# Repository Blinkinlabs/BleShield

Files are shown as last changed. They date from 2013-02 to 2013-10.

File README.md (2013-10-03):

# Blinkinlabs Bluetooth Low Energy Shield

An Arduino shield using the S-Power BG312L BLE module:
http://s-power.com.hk/BG312L.html

This shield is designed for the serial version of the module.

The BLE Shield has plenty of different peripherals that you can use to prototype your own Bluetooth Low Energy designs: three buttons, one RGB led, and an output to control one digital RGB LED strip.

The BLE Shield has been tested on the Arduino Duemilanove, Uno, and Leonardo. It has been confirmed to work with the iPad Mini running the free LightBlue application, and should work fine with iPhone 4S, iPhone5, and iPad Retina running iOS 5 and 6. The iPad 2 does not support Bluetooth 4.0 (BLE). Android support for BLE is unfortunately incomplete but in active development. Support for MacOS, Windows, and Linux is currently untested but seems to be in active development.

We're currently working on demo applications for iOS and computers, but in the mean time, you can communicate with your BLE Shield using the free LightBlue application by Punch Through, available on the app store. There are several other BLE iOS apps available that should work as well.

The BG312L module is based on the [TI CC2541][ti] Bluetooth 4.0 chip. More information, as well as sample iOS code, is available on [TI's Wiki][ti-wiki].

Let us know what cool things you do with the BLE Shield!

# Arduino Library and Demo Sketch

From the `library` folder, copy the `Blinkinlabs_BLEShield` folder to your Arduino `libraries` folder. Restart the Arduino IDE, then open File->Sketchbook->libraries->Blinkinlabs_BLEShield->BLEShield. Upload to your Arduino and follow the instructions on our [website][ble] to connect to the shield using your Bluetooth 4.0 compatible device. Enjoy!

[ti]: http://www.ti.com/product/cc2541
[ti-wiki]: http://processors.wiki.ti.com/index.php/Category:BluetoothLE

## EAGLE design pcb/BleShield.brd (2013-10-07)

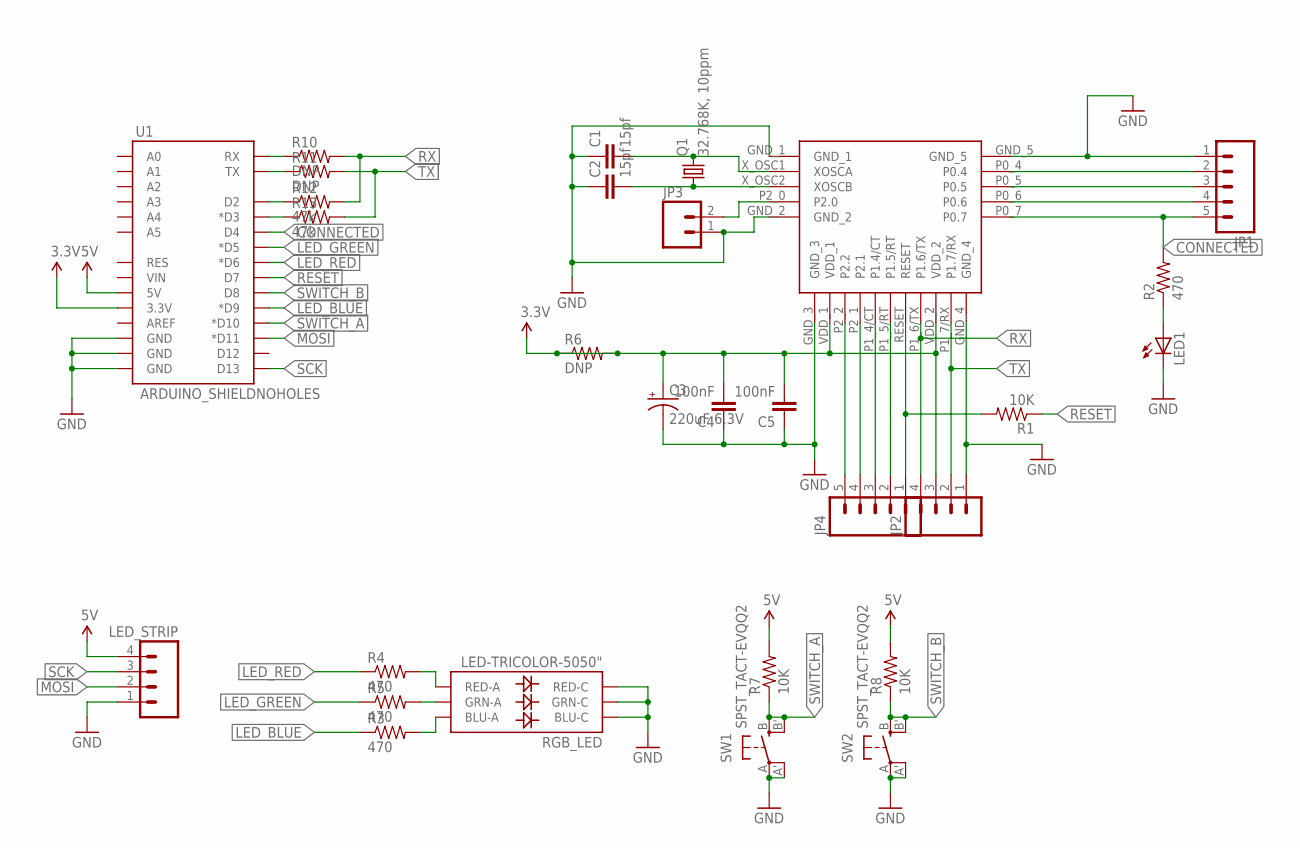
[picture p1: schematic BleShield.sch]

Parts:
C1, C2: 15pf; 0805
C3: 220uF 6.3V; C/6032-28R
C4, C5: 100nF; 0805
JP1, JP4: M051.27MM; 1X05-1.27MM
JP2: M041.27MM; 1X04-1.27MM
JP3: M02; 1X02-1.27MM
LED1: LEDCHIPLED_0805; CHIPLED_0805
LED_STRIP: M04PTH; 1X04
Q1: 32.768K, 10ppm; CRYSTAL_3215
R1, R7, R8: 10K; 0805
R2, R3, R4, R5: 470; 0805
R6, R10, R11: DNP; 0805
R12, R13: 47k; 0805
RGB_LED: LED-TRICOLOR-5050"; LED-TRICOLOR-5050-FIXED
SW1, SW2: SPST_TACT-EVQQ2; EVQ-Q2
U1: ARDUINO_SHIELDNOHOLES; DUEMILANOVE_SHIELD_NOHOLES
U$1: BG213L; BG312L

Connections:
3.3V: C3.+, C4.2, C5.2, JP2.3, R6.1, R6.2, U1.3.3V, U$1.VDD_1, U$1.VDD_2
5V: LED_STRIP.4, R7.2, R8.2, U1.5V
CONNECTED: JP1.5, R2.2, U1.D4, U$1.P0_7 (P0.7)
GND: C1.1, C2.1, C3.-, C4.1, C5.1, JP1.1, JP2.1, JP3.1, LED1.C, LED_STRIP.1, RGB_LED.1 (BLU-C), RGB_LED.2 (RED-C), RGB_LED.3 (GRN-C), SW1.A, SW1.A' (P1), SW2.A, SW2.A' (P1), U1.GND@0 (GND), U1.GND@1 (GND), U1.GND@2 (GND), U$1.GND_1, U$1.GND_2, U$1.GND_3, U$1.GND_4, U$1.GND_5
LED_BLUE: R3.1, U1.D9 (*D9)
LED_GREEN: R5.1, U1.D5 (*D5)
LED_RED: R4.1, U1.D6 (*D6)
MOSI: LED_STRIP.2, U1.D11 (*D11)
unnamed: JP4.1, R1.2, U$1.RESET
unnamed: R3.2, RGB_LED.6 (BLU-A)
unnamed: C1.2, Q1.P$2 (2), U$1.X_OSC1 (XOSCA)
unnamed: C2.2, Q1.P$1 (1), U$1.X_OSC2 (XOSCB)
unnamed: R5.2, RGB_LED.4 (GRN-A)
unnamed: R4.2, RGB_LED.5 (RED-A)
unnamed: LED1.A, R2.1
unnamed: JP4.5, U$1.P2_2 (P2.2)
unnamed: R12.1, U1.D2
unnamed: R10.1, U1.RX
unnamed: R11.1, U1.TX
unnamed: JP4.4, U$1.P2_1 (P2.1)
unnamed: JP4.3, U$1.P1_4/CT (P1.4/CT)
unnamed: JP4.2, U$1.P1_5/RT (P1.5/RT)
unnamed: JP1.2, U$1.P0_4 (P0.4)
unnamed: JP1.3, U$1.P0_5 (P0.5)
unnamed: JP1.4, U$1.P0_6 (P0.6)
unnamed: JP3.2, U$1.P2_0 (P2.0)
unnamed: R13.1, U1.D3 (*D3)
RESET: R1.1, U1.D7
RX: JP2.4, R10.2, R12.2, U$1.P1_6/TX (P1.6/TX)
SCK: LED_STRIP.3, U1.D13
SWITCH_A: R7.1, SW1.B (S), SW1.B' (S1), U1.D10 (*D10)
SWITCH_B: R8.1, SW2.B (S), SW2.B' (S1), U1.D8
TX: JP2.2, R11.2, R13.2, U$1.P1_7/RX (P1.7/RX)

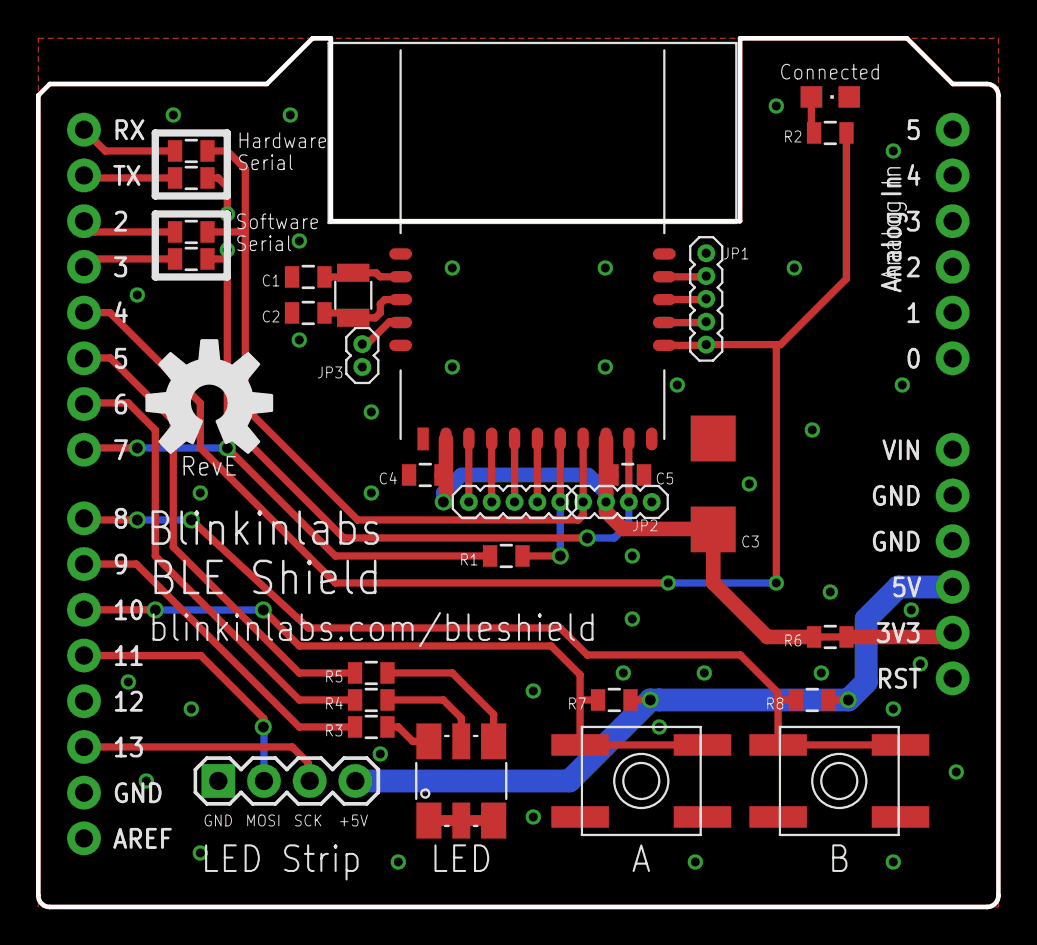
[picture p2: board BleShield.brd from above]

Board: 2 copper layers, 53.3 x 48.3 mm, 30 parts (0 on the bottom side), 33 nets.

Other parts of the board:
U$7: OSHW-LOGO-L

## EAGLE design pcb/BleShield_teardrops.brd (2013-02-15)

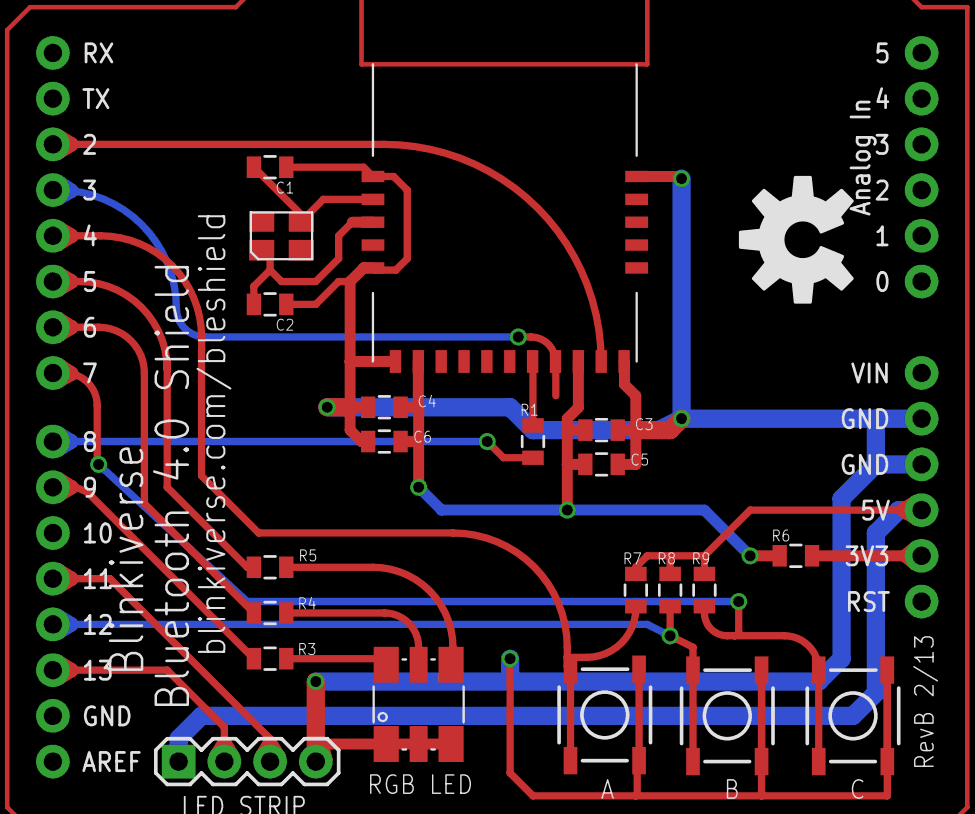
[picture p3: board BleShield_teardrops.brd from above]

Board: 2 copper layers, 23 parts (0 on the bottom side), 21 nets.

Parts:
A: TACTILE_SWITCH_SMD
B: TACTILE_SWITCH_SMD
C: TACTILE_SWITCH_SMD
C1, C2: 15pf; 0805
C3, C4: 10uf; 0805
C5, C6: 100nf; 0805
LED STRIP: 1X04
R1, R7, R8, R9: 10K; 0805
R3, R4, R5: 330; 0805
R6: 0; 0805
RGB LED: LED-TRICOLOR-5050"; LED-TRICOLOR-5050-FIXED
U1: ARDUINO_SHIELDNOHOLES; DUEMILANOVE_SHIELD_NOHOLES
U$1: BG213L; BG312L
U$7: OSHW-LOGO-L
Y1: 32.768KHz, 10 PPM; XS3225

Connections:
3.3V: R6.1, U1.3.3V
5V: LED STRIP.1, R7.2, R8.2, R9.2, U1.5V
GND: A.1, A.2, B.1, B.2, C.1, C.2, C1.1, C2.1, C3.1, C4.1, C5.1, C6.1, LED STRIP.4, RGB LED.1, RGB LED.2, RGB LED.3, U1.GND@0, U1.GND@1, U$1.GND_1, U$1.GND_2, U$1.GND_3, U$1.GND_4, U$1.GND_5
LED_BLUE: R3.1, U1.D9
LED_GREEN: R5.1, U1.D5
LED_RED: R4.1, U1.D6
MOSI: LED STRIP.3, U1.D11
unnamed: R1.2, U$1.RESET
unnamed: R3.2, RGB LED.6
unnamed: C1.2, U$1.X_OSC1, Y1.P$3
unnamed: C2.2, U$1.X_OSC2, Y1.P$1
unnamed: R5.2, RGB LED.4
unnamed: R4.2, RGB LED.5
unnamed: C3.2, C4.2, C5.2, C6.2, R6.2, U$1.VDD_1, U$1.VDD_2
RESET: R1.1, U1.D8
RX: U1.D2, U$1.P1_7/RX
SCK: LED STRIP.2, U1.D13
SWITCH_A: A.3, A.4, R7.1, U1.D4
SWITCH_B: B.3, B.4, R8.1, U1.D12
SWITCH_C: C.3, C.4, R9.1, U1.D7
TX: U1.D3, U$1.P1_6/TX

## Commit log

2012-12-16 Working version
    [BleShield.brd, BleShield.sch]
2012-12-16 Move PCB design to its own directory.
    [BleShield.brd, BleShield.sch]
2012-12-16 Preliminary design finished.
    [BleShield.brd, BleShield.sch]
2012-12-17 Add option to use software serial port, make the board smaller, etc.
    [BleShield.brd, BleShield.sch]
2012-12-17 label most of the things
    [BleShield.brd, BleShield.sch]
2012-12-20 Updat bom
2012-12-31 RevA version, as shipped.
    [BleShield.brd]
2013-01-15 Remove R2 resistor
    [BleShield.brd, BleShield.sch]
2013-02-14 fixed LED pinout, changed crystal to 3225 package
    [BleShield.brd, BleShield.sch]
2013-02-14 messed with the silkscreens
    [BleShield.brd]
2013-02-15 fixed silkscreens, minor re-routing, added teardrops
    [BleShield.sch, BleShield_teardrops.brd]
2013-02-16 fixed LED strip header, minor re-routing
    [BleShield.brd, BleShield.sch]
2013-02-16 re-did teardrops
    [BleShield_teardrops_B2-16.brd]
2013-02-16 added code to drive the LED strip
2013-03-27 Update documentation, layout
    [BleShield.brd, BleShield.sch]
2013-03-27 Add keepaway, cutout to BLE part, knock out some to-do items.
    [BleShield.brd, BleShield.sch]
2013-03-27 Swap out programming headers to 1.27mm, to match module pitch (only a master will use these anyway?)
    [BleShield.brd, BleShield.sch]
2013-03-30 Knocked out everything except crystal pad and RX/TX doublecheck.
    [BleShield.brd, BleShield.sch]
2013-04-01 Fix RX/TX line assignment
    [BleShield.brd, BleShield.sch]
2013-04-01 RevC release candidate
    [BleShield.brd, BleShield.sch]
2013-04-02 On Samson's recommendation, add ground planes on top&bottom layers under module.
    [BleShield.brd, BleShield.sch]
2013-04-11 Add 47K resistor to work around the voltage difference problem
    [BleShield.brd, BleShield.sch]
2013-10-03 Name change
    [BleShield.brd]
2013-10-07 Update library name
    [BleShield.brd, BleShield.sch]

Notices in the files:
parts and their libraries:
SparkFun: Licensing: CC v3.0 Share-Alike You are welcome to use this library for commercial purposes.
